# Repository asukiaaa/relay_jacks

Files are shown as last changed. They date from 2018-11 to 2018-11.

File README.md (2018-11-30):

# relay_jacks

A KiCad pcb project for jacks controlled by relay.

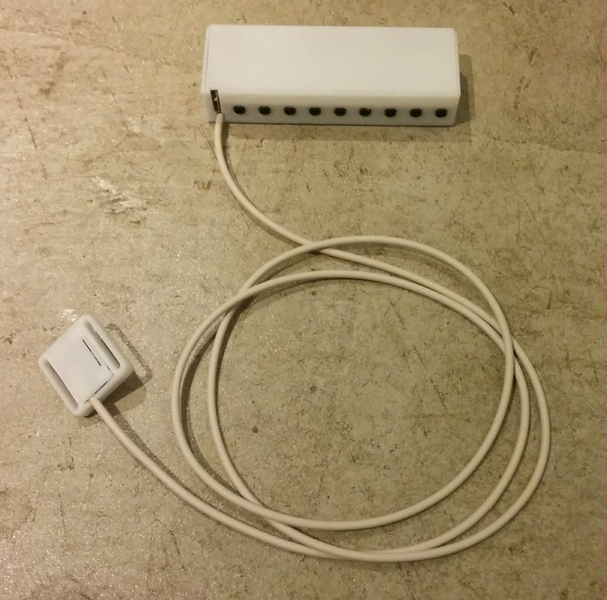
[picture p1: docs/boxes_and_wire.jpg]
boxes_and_wire

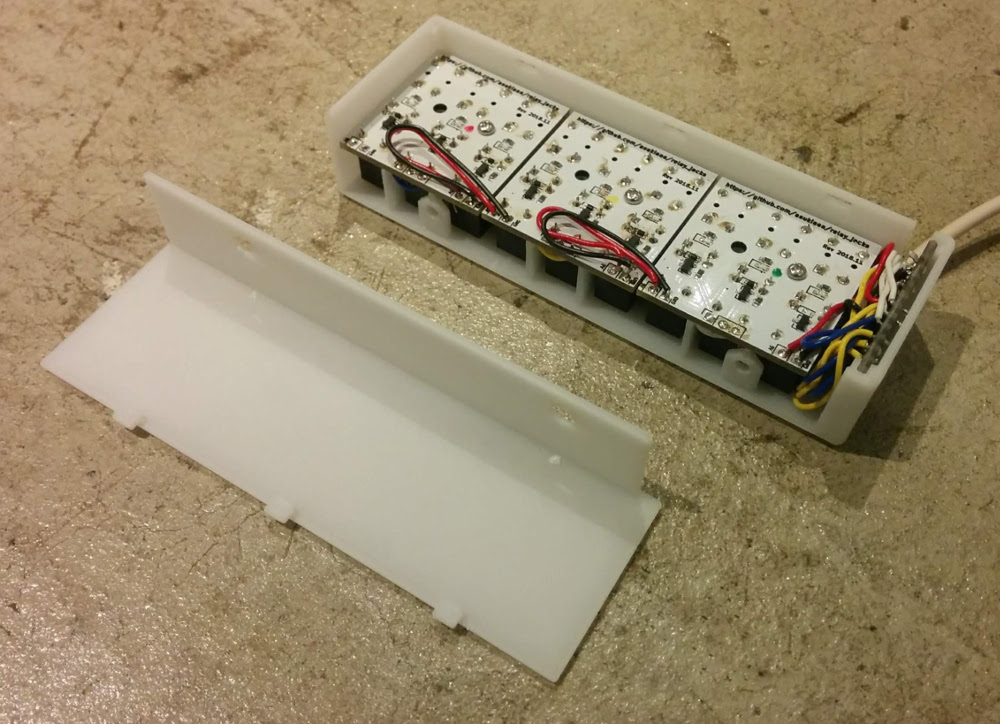
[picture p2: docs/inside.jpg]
inside

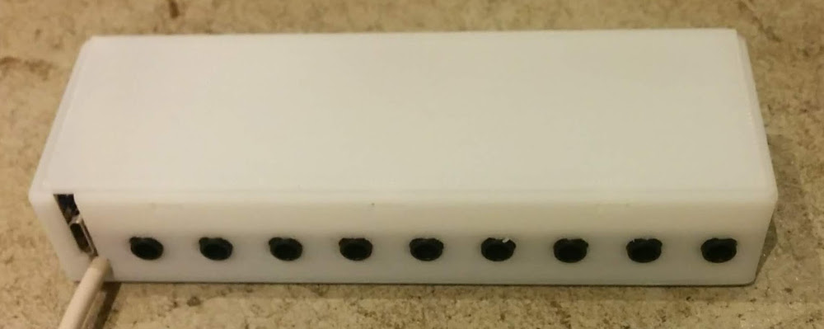
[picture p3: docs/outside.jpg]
outside


[mpu9250-25mm-belt-holder](https://github.com/asukiaaa/mpu9250-25mm-belt-holder) is used for a sensor case.

# Components

- [Relay](http://akizukidenshi.com/catalog/g/gP-01346/)
- [Mosfet](http://akizukidenshi.com/catalog/g/gI-04256/)
- [Diode](http://akizukidenshi.com/catalog/g/gI-06467/)
- [Resistor 1k](http://akizukidenshi.com/catalog/g/gR-06102/)
- [3.5mm audio jack](http://akizukidenshi.com/catalog/g/gC-02460/)
- [LED Green](http://akizukidenshi.com/catalog/g/gI-06417/)
- [LED Yellow](http://akizukidenshi.com/catalog/g/gI-03984/)
- [LED Red](http://akizukidenshi.com/catalog/g/gI-03978/)

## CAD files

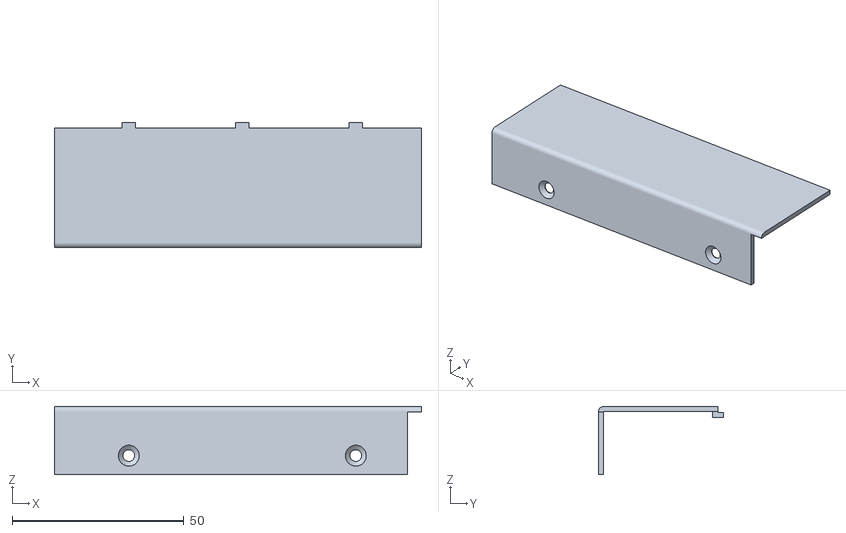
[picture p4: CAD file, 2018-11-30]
case/cover.stl
106.7 x 36.4 x 19.8

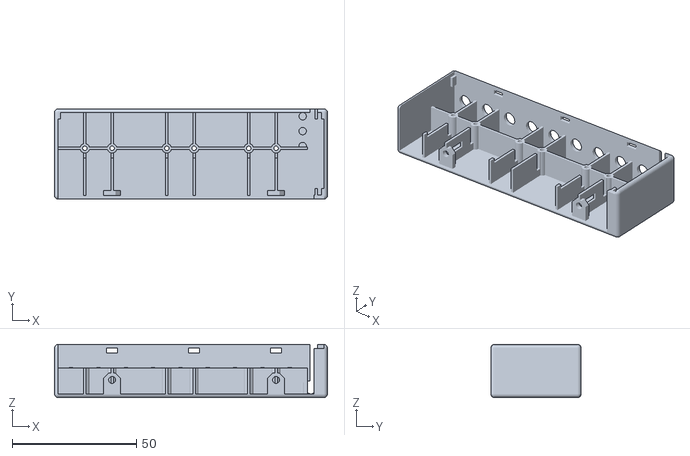
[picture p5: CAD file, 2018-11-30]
case/body.stl
109.9 x 36.4 x 21.4

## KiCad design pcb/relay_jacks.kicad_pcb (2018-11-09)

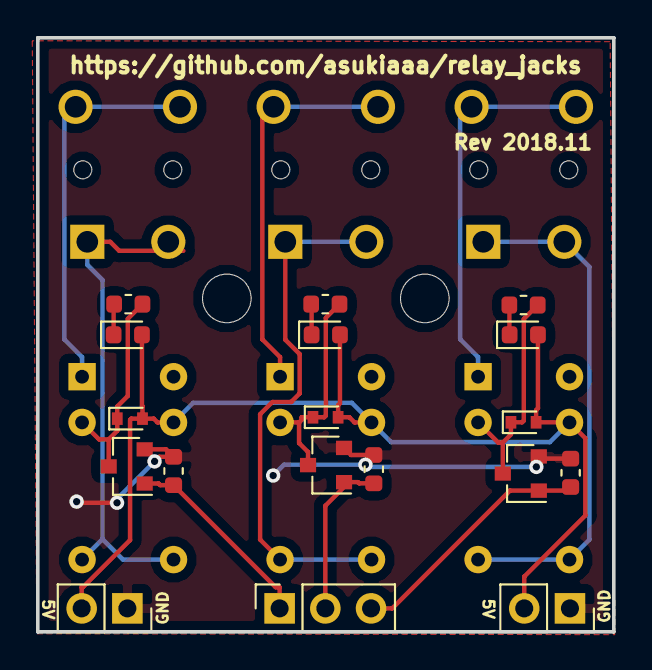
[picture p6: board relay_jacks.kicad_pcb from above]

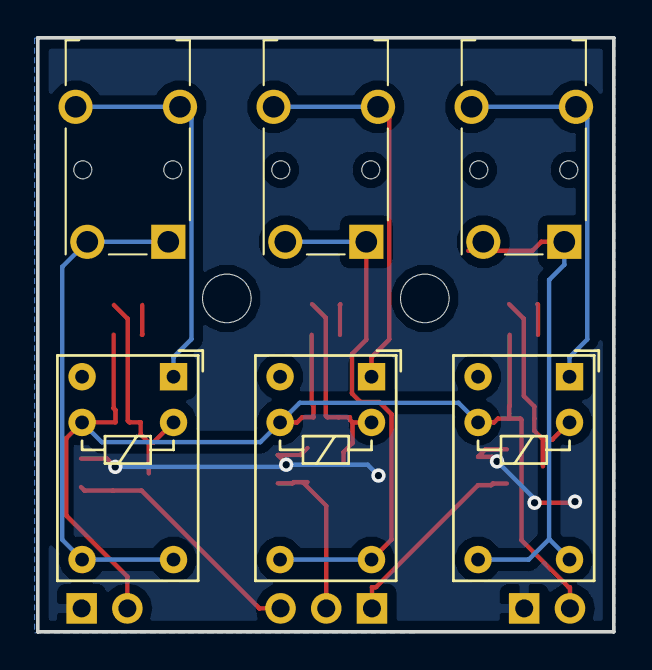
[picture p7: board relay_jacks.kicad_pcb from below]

Board: 2 copper layers, 32.0 x 33.0 mm, 26 parts (6 on the bottom side), 17 nets.

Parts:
D1, D3, D5: LED; LED_0603_1608Metric
D2, D4, D6: DIODE; D_SOD-523
J1, J5, J6: AudioJack3_Ground; Jack_3.5mm_Switronic_ST-005-G_horizontal
J2: Conn_01x03; PinSocket_1x03_P2.54mm_Vertical
J3, J4: Conn_01x02; PinSocket_1x02_P2.54mm_Vertical
K1, K2, K3: Y14x-1C-xxDS; Relay_SPDT_HsinDa_Y14
Q1, Q2, Q3: Q_NMOS_GSD; SOT-23
R1, R2, R3, R4, R5, R6: 1k; R_0603_1608Metric
REF1, REF2: MountingHole_2.7mm_M2.5_DIN965

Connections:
+5V: D1.2, D2.2, D3.2, D4.2, D5.2, D6.2, J3.2, J4.2, K1.4, K2.4, K3.4
GND: J3.1, J4.1, Q1.2, Q2.2, Q3.2, R2.2, R3.2, R5.2
unnamed: D1.1, R1.2
unnamed: D2.1, K1.3, Q1.3, R1.1
unnamed: D3.1, R4.2
unnamed: D4.1, K2.3, Q2.3, R4.1
unnamed: D5.1, R6.2
unnamed: D6.1, K3.3, Q3.3, R6.1
unnamed: J1.2, J1.3, K1.5, K1.6
unnamed: J1.4, K1.1
unnamed: J5.2, J5.3, K2.5, K2.6
unnamed: J5.4, K2.1
unnamed: J6.2, J6.3, K3.5, K3.6
unnamed: J6.4, K3.1
SIG0: J2.1, Q1.1, R2.1
SIG1: J2.2, Q2.1, R3.1
SIG2: J2.3, Q3.1, R5.1

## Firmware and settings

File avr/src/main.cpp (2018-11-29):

#include <Arduino.h>
#include <MPU9250_asukiaaa.h>

const unsigned long minOnMillis = 1000;
const int OUTPUT_PINS[] = {A2, A0, A1, 16, 14, 15, 6, 5, 4};
const int OUTPUT_NUM = sizeof(OUTPUT_PINS);
unsigned long outputOnAt[OUTPUT_NUM];
MPU9250 sensor;

void setup() {
  // Serial.begin(9600);
  Wire.begin();
  sensor.setWire(&Wire);
  sensor.beginAccel();
  for(int i = 0; i < OUTPUT_NUM; ++i) {
    pinMode(OUTPUT_PINS[i], OUTPUT);
    outputOnAt[i] = 0;
  }
  delay(minOnMillis);
}

void setOutputLevel(int level) {
  // Serial.println(level);
  unsigned long currentMillis = millis();
  for (int i = 0; i < OUTPUT_NUM; ++i) {
    boolean power = i < level;
    if (power) {
      outputOnAt[i] = currentMillis;
    } else if (outputOnAt[i] + minOnMillis > currentMillis) {
      power = true;
    }
    digitalWrite(OUTPUT_PINS[i], power);
  }
}

int getLevelOfAccel() {
  float accelSum = sensor.accelSqrt();
  return (int) ((accelSum - 1.1) / 0.4);
}

void loop() {
  sensor.accelUpdate();
  setOutputLevel(getLevelOfAccel());
  delay(80);
}

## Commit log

2018-11-07 Create pcb directory
    [relay_jacks-B.Cu.gbr, relay_jacks-B.Mask.gbr, relay_jacks-B.Paste.gbr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]
2018-11-07 Export partial model for testing
    [case.stl]
2018-11-07 Adjust case size with referencing test result
2018-11-09 Add a hole for wire
2018-11-09 Update pcb design as rev 2018.11
    [relay_jacks-B.Cu.gbr, relay_jacks-B.Mask.gbr, relay_jacks-B.Paste.gbr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]
2018-11-09 Update cover design for new pcb
2018-11-15 Add pillow to fix wire to body of case
2018-11-16 Export stl for testing
    [body.stl, case.stl, cover.stl]
2018-11-18 Update clearance of cover and hook hole
2018-11-18 Change number, position and hole style for mounting holes
2018-11-19 Correct pcb hole position
2018-11-19 Update mountingHoleRadius as 2.0 / 2mm for M2 screw
2018-11-19 Add chamfer for usb and wire hole connection
2018-11-19 Update stl for testing
    [body.stl, cover.stl]
2018-11-21 Update body stl file
    [body.stl]
2018-11-22 Add chamfer again between usb and wire holes
2018-11-22 Update stl files
    [body.stl, cover.stl]
2018-11-22 Add *.pyc to case/.gitignore
2018-11-23 Change mouting hole size smaller as 1.8mm from 2.0mm
2018-11-23 Set moutingHoleBaseLength as 2.0mm
2018-11-24 Rename wire as sensorWire
2018-11-24 Add relayWireSpace
2018-11-24 Change y of relaysPcbHolePositions
2018-11-25 Remove holeClearance
2018-11-28 Change size of relayWireSpace
    [body.stl]
2018-11-29 Add side space for wire
    [body.stl]
2018-11-30 Export stl as full size
    [body.stl, cover.stl]
2018-11-30 Add link of mpu9250 case
